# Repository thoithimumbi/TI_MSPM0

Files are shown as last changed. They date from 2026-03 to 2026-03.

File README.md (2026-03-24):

# Low-Power MSPM0 Sensor Node with USB-C Connectivity

## System Overview
The board is powered via a USB-C connector, providing a primary 5V rail which is regulated to 3.3V for the MCU and onboard peripherals.

The system integrates:
- A high-performance ARM Cortex-M0+ microcontroller  
- A USB-to-UART bridge for direct serial communication  
- A 3-axis accelerometer for motion sensing applications  

---

## Functional Blocks

### Power Management
- **Input:** +5V from USB VBUS  
- **Regulation:** SPX3819M5-L-3-3 LDO → 3.3V rail  
- **Filtering:**
  - 10 µF (bulk)
  - 470 nF (high-frequency bypass)

Decoupling capacitors are placed on both input and output stages to reduce noise and ensure rail stability.

---

### Microcontroller (TI MSPM0G3507)
The MSPM0G3507PTR (LQFP-48) serves as the central processing unit.

**Key configurations:**
- **Clocking:**  
  External 8 MHz crystal (X1) with 15 pF load capacitors for precise timing  

- **Programming & Debugging:**  
  TC2030 SWD header (SWDIO / SWCLK) for firmware flashing and real-time debugging  

- **Reset Circuit:**  
  - 5.1 kΩ pull-up resistor  
  - 470 nF capacitor for noise filtering  
  Ensures stable and reliable startup behavior  

---

### USB-to-UART Interface
- **IC:** CH340E USB-to-serial converter  
- **Function:** Bridges USB differential pair (D+ / D−) to MCU UART  

**Connections:**
- PA0 → TX  
- PA1 → RX  

**Protection:**
- USBLC6-2SC6 ESD diode array on USB lines  
- Safeguards against electrostatic discharge and hot-plug transients  

---

### Sensors & Peripherals

#### LIS2DH Accelerometer
A low-power, high-resolution 3-axis accelerometer integrated on the 3.3V domain.

- **Interface:** I2C  
  - SDA → PA10  
  - SCL → PA11  
  - Pull-ups: 5.1 kΩ  

- **Interrupts:**
  - INT1 → PB8  
  - INT2 → PB9  

Supports interrupt-driven operation, enabling:
- Motion-triggered events  
- Low-power sleep modes with wake-on-interrupt  

---

## Technical Specifications

| Component | Description |
|---|---|
| MCU | TI MSPM0G3507 (ARM Cortex-M0+, up to 80 MHz) |
| USB Connector | USB-C (USB 2.0 Full Speed) |
| Interface IC | CH340E USB-to-UART |
| Voltage Rails | 5V (USB), 3.3V (LDO Output) |
| Accelerometer | LIS2DH (3-axis) |
| I2C Address | Configurable via hardware |
| PCB Features | 4× M3 mounting holes, 3× fiducials |

---

## Connectivity Table (Key Signals)

| Function  | MCU Pin | Peripheral |
|---|---|---|
| UART TX  | PA0 | CH340E RXD |
| UART RX  | PA1 | CH340E TXD |
| I2C SDA  | PA10 | LIS2DH SDA |
| I2C SCL  | PA11 | LIS2DH SCL |
| SWDIO | PA19 | TC2030 (Pin 2) |
| SWCLK | PA20 | TC2030 (Pin 4) |

---

## Design Notes
- External crystal ensures accurate UART baud rates and I2C timing  
- Interrupt-driven accelerometer minimizes power consumption  
- USB ESD protection improves reliability in real-world usage  
- Tag-Connect header reduces footprint while maintaining debug access  

---

## Media
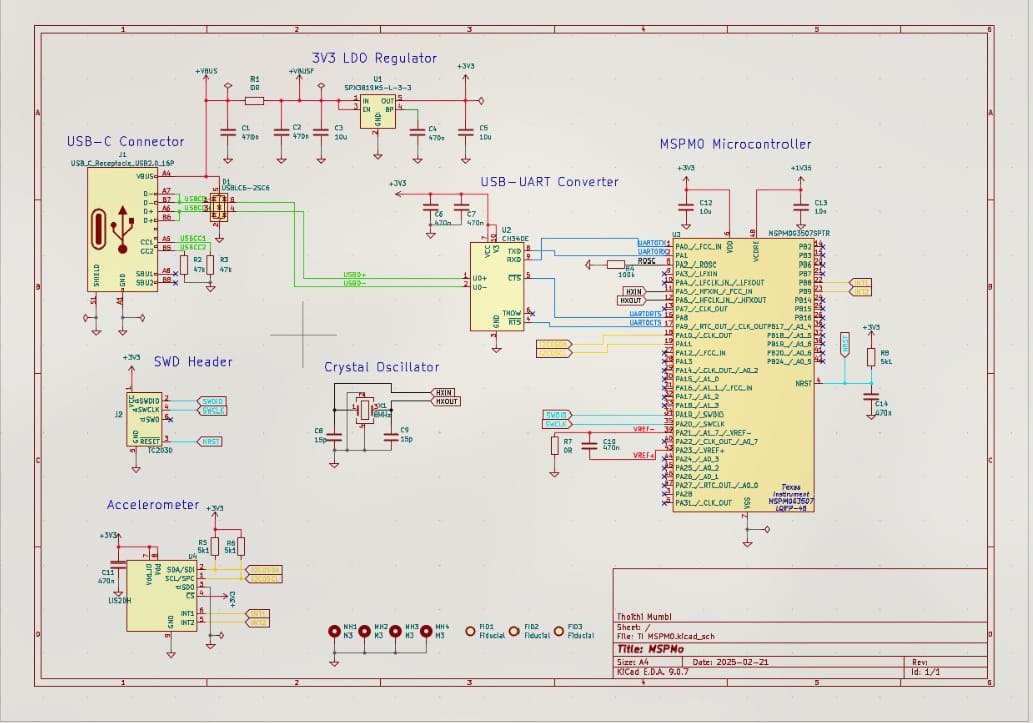
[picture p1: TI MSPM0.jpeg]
Schematic

<p align="center">
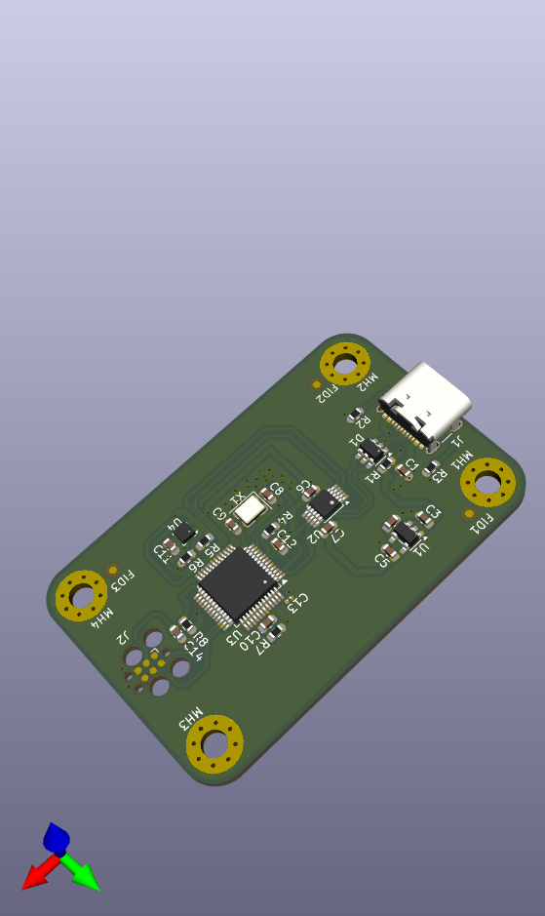
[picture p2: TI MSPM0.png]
3D Image
  
</p>

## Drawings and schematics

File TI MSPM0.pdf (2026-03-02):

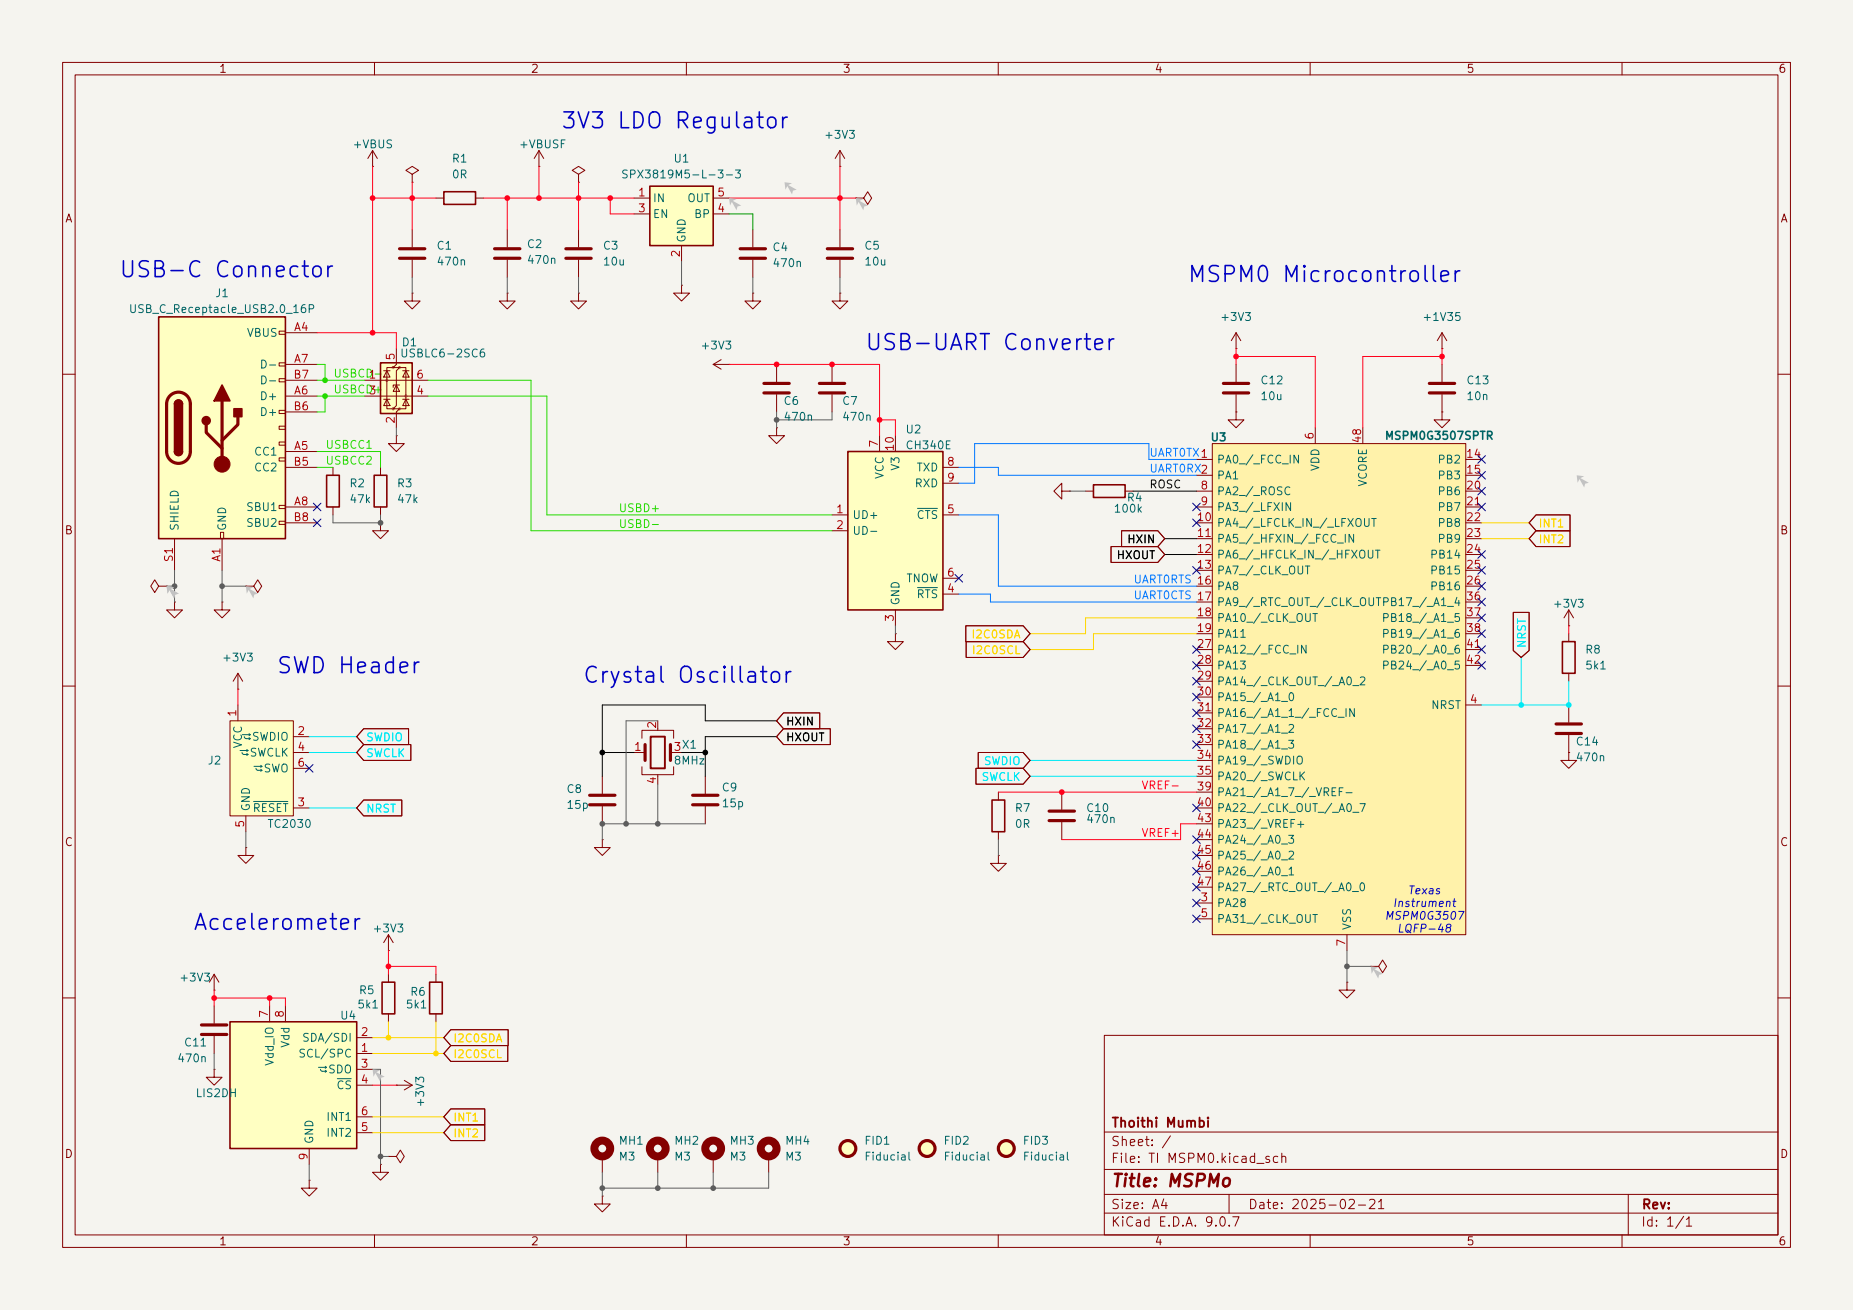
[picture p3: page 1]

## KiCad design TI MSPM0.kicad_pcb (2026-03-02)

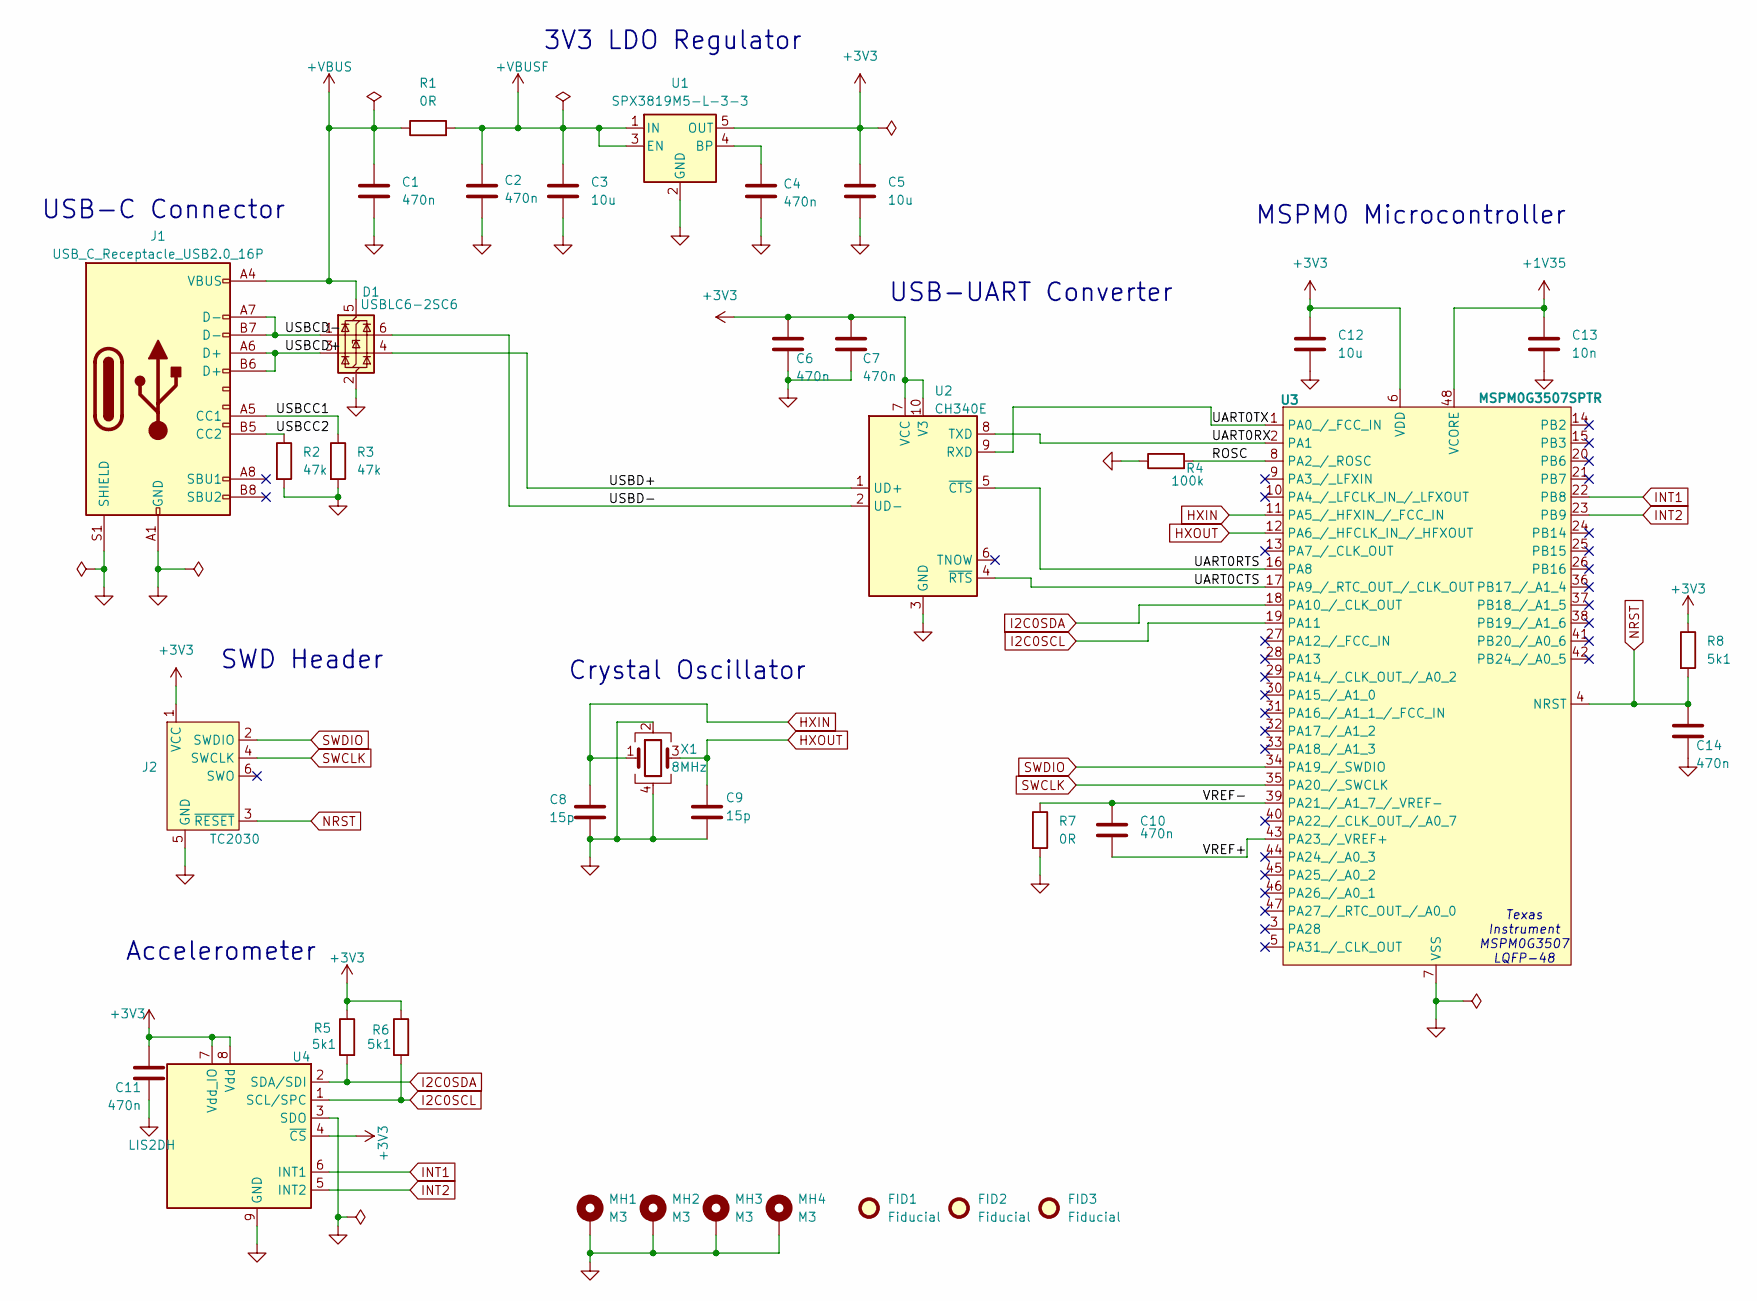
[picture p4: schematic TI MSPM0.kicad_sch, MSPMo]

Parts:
C1, C2, C4, C6, C7, C10, C11, C14: 470n; C_0603_1608Metric
C3, C5, C12: 10u; C_0603_1608Metric
C8, C9: 15p; C_0603_1608Metric
C13: 10n; C_0201_0603Metric
D1: USBLC6-2SC6; SOT-23-6
FID1, FID2, FID3: Fiducial; Fiducial_1mm_Mask2mm
J1: USB_C_Receptacle_USB2.0_16P; USB_C_Receptacle_GCT_USB4105-xx-A_16P_TopMnt_Horizontal
J2: TC2030; Tag-Connect_TC2030-IDC-FP_2x03_P1.27mm_Vertical
MH1, MH2, MH3, MH4: M3; MountingHole_3.2mm_M3_Pad_Via
R1, R7: 0R; R_0603_1608Metric
R2, R3: 47k; R_0603_1608Metric
R4: 100k; R_0603_1608Metric
R5, R6, R8: 5k1; R_0603_1608Metric
U1: SPX3819M5-L-3-3; SOT-23-5
U2: CH340E; MSOP-10_3x3mm_P0.5mm
U3: MSPM0G3507SPTR; LQFP-48_7x7mm_P0.5mm
U4: LIS2DH; LGA-14_2x2mm_P0.35mm_LayoutBorder3x4y
X1: 8MHz; Crystal_SMD_3225-4Pin_3.2x2.5mm

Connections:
+1V35: C13.1, U3.48 (VCORE)
+3V3: C5.1, C6.1, C7.1, C11.1, C12.1, J2.1 (VCC), R5.1, R6.1, R8.1, U1.5 (OUT), U2.7 (VCC), U2.10 (V3), U3.6 (VDD), U4.4 (~CS), U4.7 (Vdd_IO), U4.8 (Vdd)
+VBUS: C1.1, D1.5 (VBUS), J1.A4 (VBUS), J1.A9 (VBUS), J1.B4 (VBUS), J1.B9 (VBUS), R1.1
+VBUSF: C2.1, C3.1, R1.2, U1.1 (IN), U1.3 (EN)
/ROSC: R4.2, U3.8 (PA2_/_ROSC)
/UART0CTS: U2.4 (~RTS), U3.17 (PA9_/_RTC_OUT_/_CLK_OUT)
/UART0RTS: U2.5 (~CTS), U3.16 (PA8)
/UART0RX: U2.8 (TXD), U3.2 (PA1)
/UART0TX: U2.9 (RXD), U3.1 (PA0_/_FCC_IN)
/USBCC1: J1.A5 (CC1), R3.1
/USBCC2: J1.B5 (CC2), R2.1
/USBCD+: D1.3 (I/O2), J1.A6 (D+), J1.B6 (D+)
/USBCD-: D1.1 (I/O1), J1.A7 (D-), J1.B7 (D-)
/USBD+: D1.4 (I/O2), U2.1 (UD+)
/USBD-: D1.6 (I/O1), U2.2 (UD-)
/VREF+: C10.2, U3.43 (PA23_/_VREF+)
/VREF-: C10.1, R7.1, U3.39 (PA21_/_A1_7_/_VREF-)
GND: C1.2, C2.2, C3.2, C4.2, C5.2, C6.2, C7.2, C8.2, C9.2, C11.2, C12.2, C13.2, C14.2, D1.2 (GND), J1.A1 (GND), J1.A12 (GND), J1.B1 (GND), J1.B12 (GND), J1.S1 (SHIELD), J2.5 (GND), MH1.1, MH2.1, MH3.1, MH4.1, R2.2, R3.2, R4.1, R7.2, U1.2 (GND), U2.3 (GND), U3.7 (VSS), U4.3 (SDO), U4.9 (GND), U4.10 (GND), U4.11 (GND), U4.12 (GND), U4.13 (GND), U4.14 (GND), X1.2, X1.4
HXIN: C8.1, U3.11 (PA5_/_HFXIN_/_FCC_IN), X1.1
HXOUT: C9.1, U3.12 (PA6_/_HFCLK_IN_/_HFXOUT), X1.3
I2C0SCL: R6.2, U3.19 (PA11), U4.1 (SCL/SPC)
I2C0SDA: R5.2, U3.18 (PA10_/_CLK_OUT), U4.2 (SDA/SDI)
INT1: U3.22 (PB8), U4.6 (INT1)
INT2: U3.23 (PB9), U4.5 (INT2)
NRST: C14.1, J2.3 (~RESET), R8.2, U3.4 (NRST)
unnamed: C4.1, U1.4 (BP)
SWCLK: J2.4 (SWCLK), U3.35 (PA20_/_SWCLK)
SWDIO: J2.2 (SWDIO), U3.34 (PA19_/_SWDIO)

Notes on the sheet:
USB-C Connector
SWD Header
Crystal Oscillator
3V3 LDO Regulator
MSPM0 Microcontroller
Accelerometer
USB-UART Converter
Texas Instrument MSPM0G3507 LQFP-48

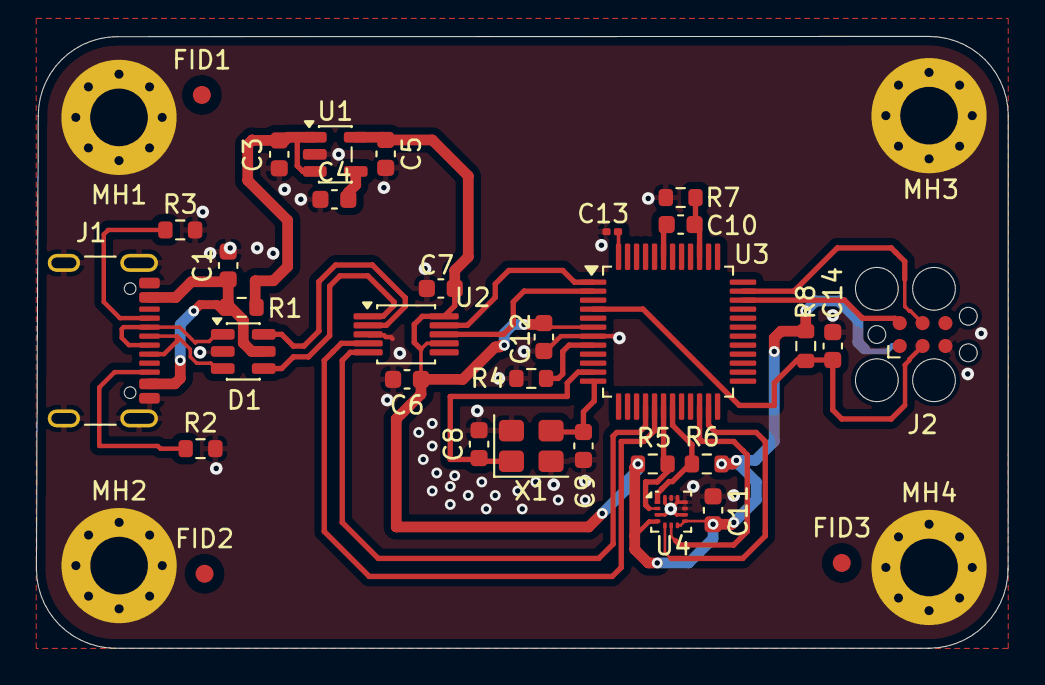
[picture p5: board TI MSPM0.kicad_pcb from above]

Board: 2 copper layers, 54.0 x 34.0 mm, 36 parts (0 on the bottom side), 28 nets.

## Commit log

2026-03-02 Add README.md for MSPM0-Based USB Development Board
2026-03-03 Add PNG schematic image to README
    Added a PNG version of the schematic to the README.
2026-03-03 Update image in README from schematic to 3D
